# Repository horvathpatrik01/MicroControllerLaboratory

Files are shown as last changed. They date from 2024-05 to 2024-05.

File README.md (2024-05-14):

BME AUT University project

<b>Ambient lighting</b>

Task: \
Create an additional hardware unit for the STM32 NUCLEO-F446RE kit, which is programmable mood lighting with three high brightness RGB LEDs.

Requirements: \
&nbsp;&nbsp;&nbsp;&nbsp;-The executable lighting programs should be editable on PC, the hardware should communicate with PC via serial port. The serial
virtual serial port for serial communication, which can be connected to the USB port on the USB port! \
&nbsp;&nbsp;&nbsp;&nbsp;-The programs created in this way are stored in an I2C EEPROM or SPI Flash memory. \
&nbsp;&nbsp;&nbsp;&nbsp;-The device should be able to generate an emulation program without programming, which the nature of which can be set by means of a push-button. \
&nbsp;&nbsp;&nbsp;&nbsp;-Use the same button to switch between downloaded lighting programs. \
&nbsp;&nbsp;&nbsp;&nbsp;-Design, construction and installation of the circuit prepare a test program system for demonstration purposes to demonstrate the device, including a microcontroller program to ensure proper operation and a PC client program.

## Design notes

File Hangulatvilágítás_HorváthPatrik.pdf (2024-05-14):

# Hangulatvilágítás

Horváth Patrik

Feladat:

Készítsen kiegészítő hardver egységet az STM32 NUCLEO-F446RE kithez, amely programozható hangulatvilágítást valósít meg három nagy fényerejű RGB LED segítségével. A végrehajtható világítás-programok PC-n szerkeszthetőek legyenek, a hardver soros porton kommunikáljon a PC-vel. A soros kommunikációhoz virtuális soros portot használjon, melyet a kiten megtalálható USB port segítségével valósítson meg! Az így létrehozott programokat tárolja egy I2C EEPROM vagy SPI Flash memóriában. Az eszköz legyen képes programozás nélkül is hangulatfény programot generálni, amely jellege egy nyomógomb segítségével állítható. Ugyanezen gomb segítségével tudjon váltani a letöltött világítás-programok között. Az áramkör megtervezése, megépítése és üzembe helyezése után készítsen el egy, az eszköz bemutatására szolgáló demonstrációs célú tesztprogram rendszert, amely magában foglalja a megfelelő működést biztosító mikrokontrolleres programot, illetve egy PCs kliensprogramot.

## PCB

A tápot egy 300uF-os alu-elko szűrőkondenzátoron keresztül csatlakoztattam a mikrokontroller E5V lábához, a két nyomógombot egy-egy 1 kOhm-os ellenálláson keresztül felhúztam 3,3V-ra.

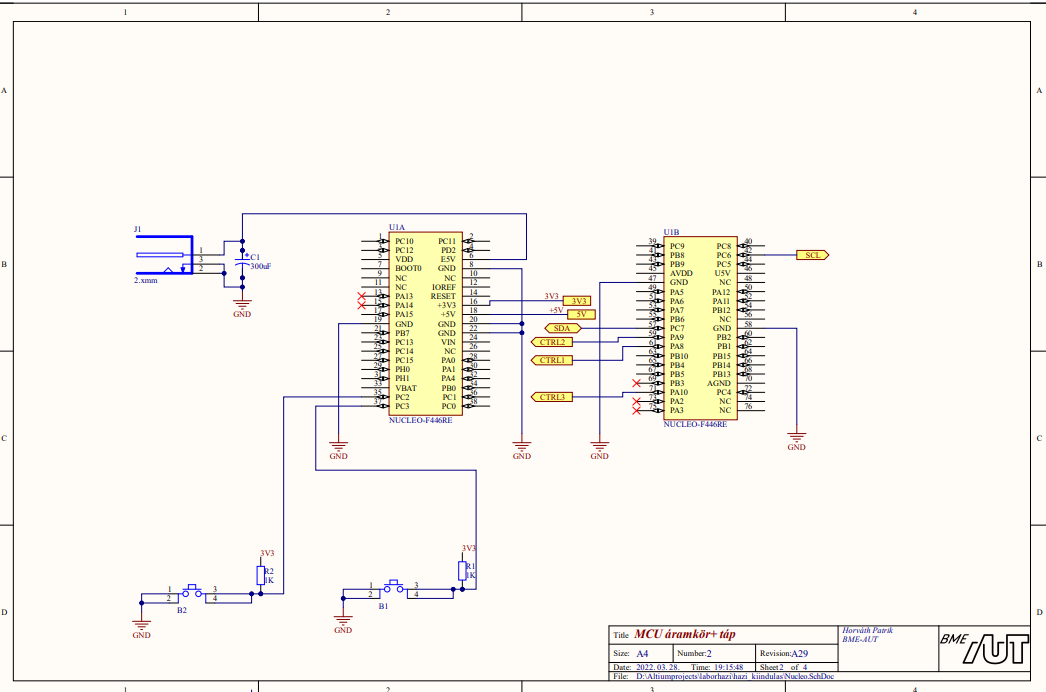
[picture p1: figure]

A ledek vezérlését Buck típusú LED Driverekkel valósítottam meg, amelyeknél a ledek áramát 100%-os kivezérlés mellett egy ellenállással lehet beállítani I=0.1/R A, ebből a képletből a közel 350mA beállításához 0,33 Ohmos ellenállásokra volt szükség. A fényerő vezérlését a CTRL lábra kötött PWM jellel lehet megvalósítani, amely nálam a TIMER1 1-es,2-es és 3-as csatornáiról érkeznek.

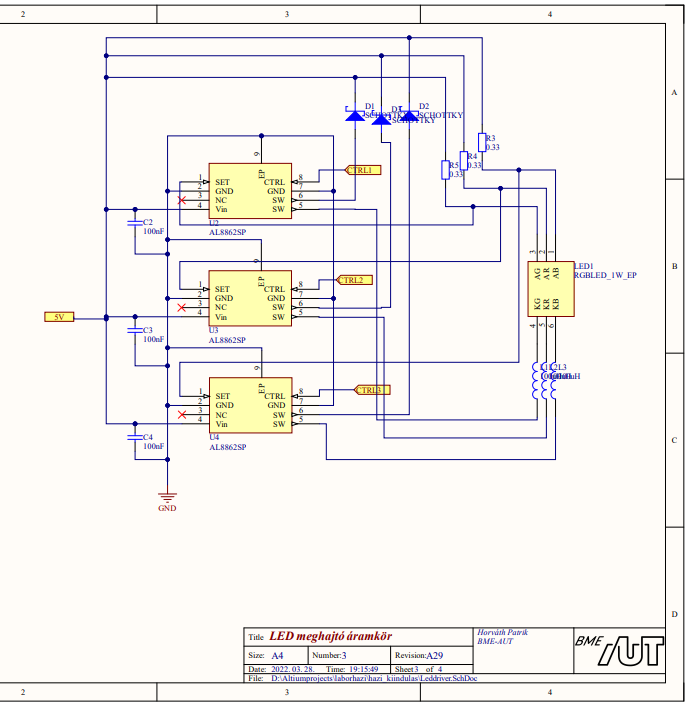
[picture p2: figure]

Az adatok tárolásához egy EEPROM-ot használtam, amely I2C-n keresztül képes adatokat küldeni illetve fogadni. Az A0-A2 lábait földre kötöttem így a 0xA0 címen lehet megcímezni. Az SDA és SCL lábakat egy-egy 10kOhmos ellenálláson keresztül fel kell húzni a tápfeszültségre az I2C működési elve miatt.

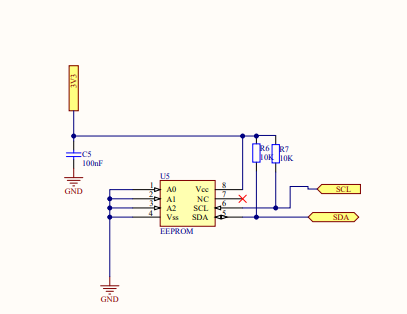
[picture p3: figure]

## Mikrokontroller firmware

A főciklusban elindítjuk a timereket, amelyeket a Ledek PWM beállítására, valamint a gombok pergésmentesítésének megoldására használunk. Ezenkívül folyamatosan meghívjuk az uartkezelő függvényt és ha szükséges akkor lekezeljük az érkezett adatokat. Az UART-on keresztül 19 bájt érkezik, és az első alapján eldönthetjük, hogy mit szeretnénk csinálni a többivel. Az utolsó két bájt az ellenőrző összeg felső és alsó 8 bitje. Ennek segítségével könnyedén ellenőrizhetjük, hogy érvényes adatokat fogadtunk-e, és ha igen akkor végrehajtjuk az utasításokat.

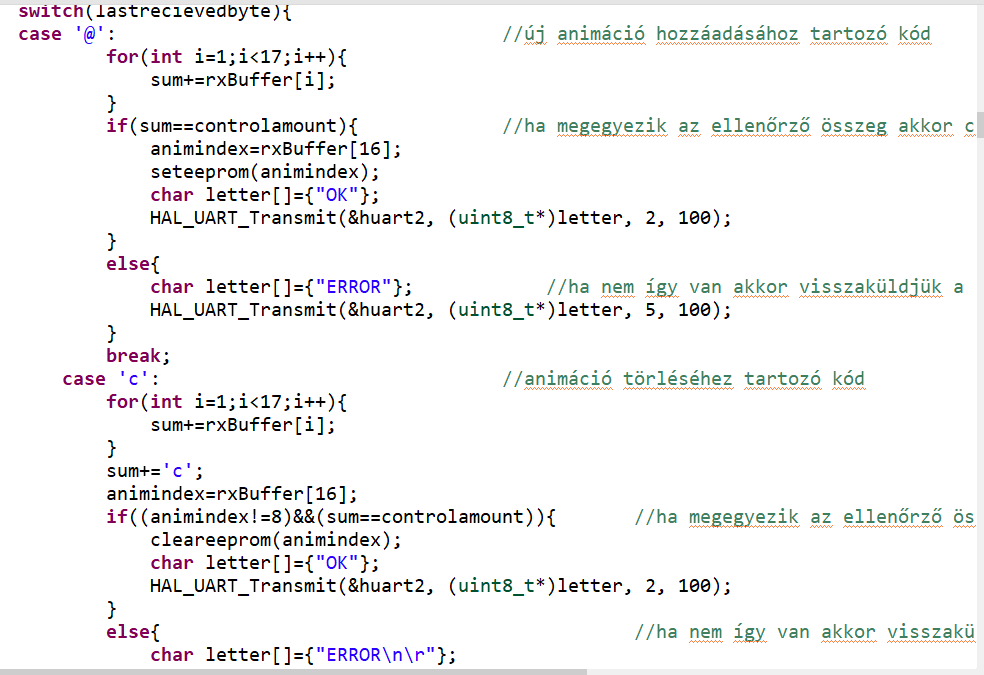
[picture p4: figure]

Nemutolsósorban pedig az animation függvényben megvizsgáljuk, hogy épp az eepromból vagy pedig előre megírt animációk közül választunk és ez alapján beállítjuk a ledeket. A kiválasztást a két nyomógombbal tudjuk elvégezni.

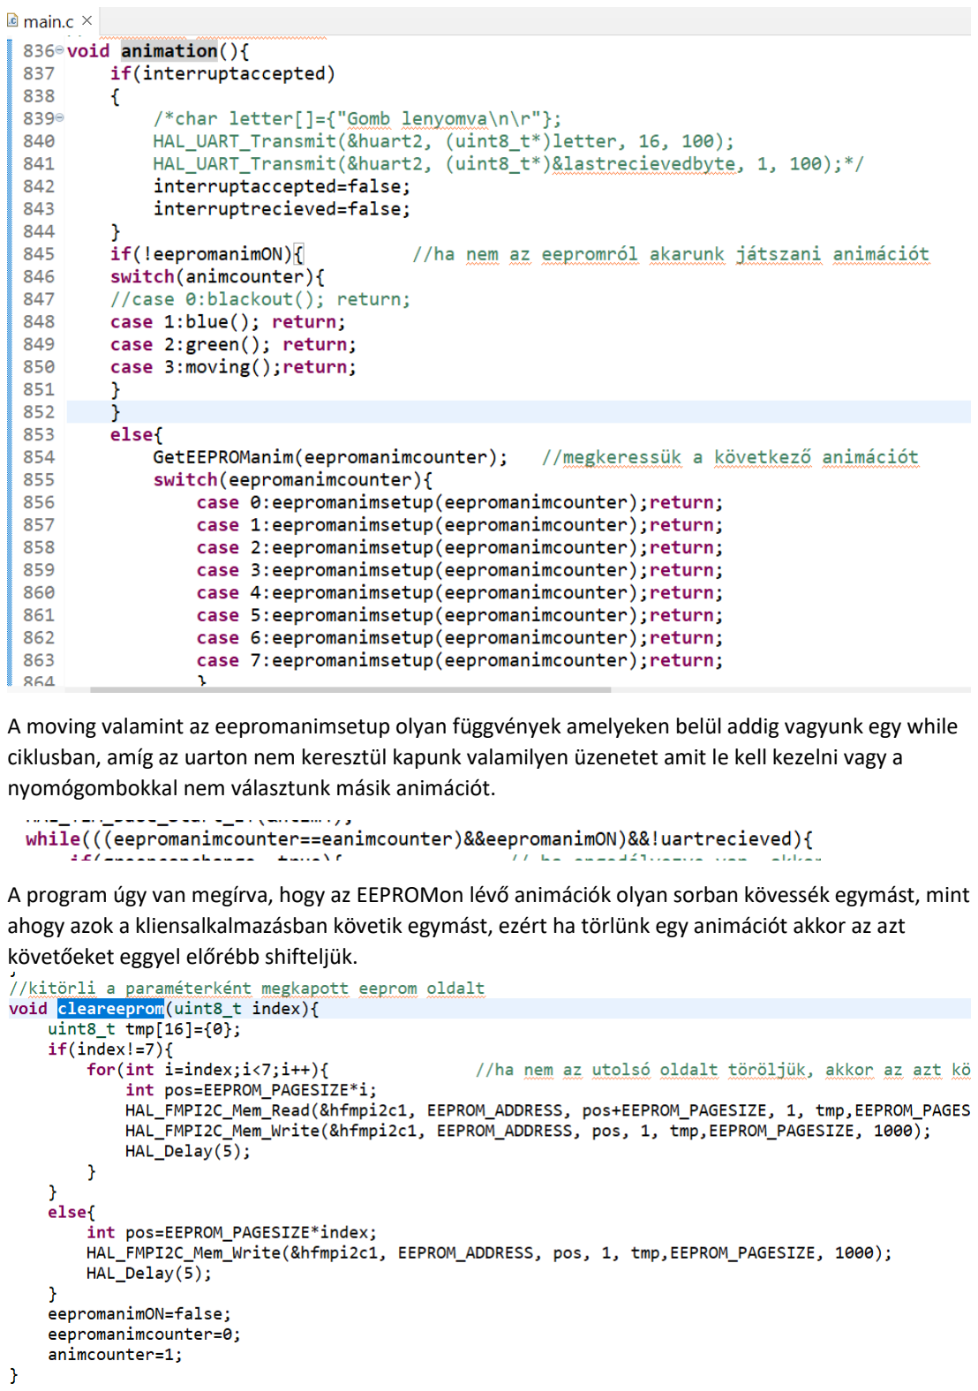
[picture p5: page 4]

A moving valamint az eepromanimsetup olyan függvények amelyeken belül addig vagyunk egy while ciklusban, amíg az uarton nem keresztül kapunk valamilyen üzenetet amit le kell kezelni vagy a nyomógombokkal nem választunk másik animációt.

A program úgy van megírva, hogy az EEPROMon lévő animációk olyan sorban kövessék egymást, mint ahogy azok a kliensalkalmazásban követik egymást, ezért ha törlünk egy animációt akkor az azt követőeket eggyel előrébb shifteljük.

## Kliensalkalmazás

Az alkalmazás megnyitása után a Settings fülön belül kiválaszthatjuk hogy melyik csatlakoztatott Portot szeretnénk használni a soros adatátvitelhez. A portokat frissítő programrészt egy timer event hív meg.

Ha a csatlakozás után készítünk egy új animációt az Animations>>New menüfül alatt akkor a Load gombunk elérhetővé válik.

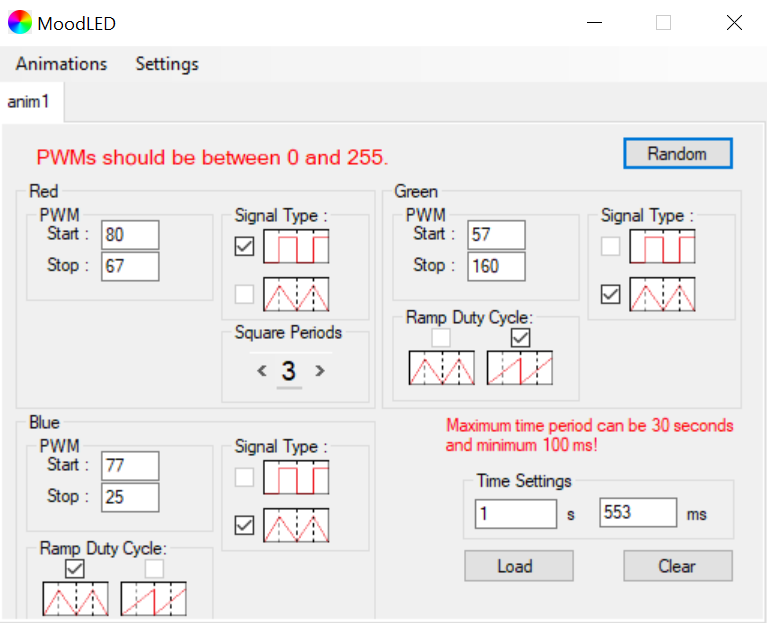
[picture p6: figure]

Itt a Random gombot használva véletlenszerű értékeket tölthetünk be a programba vagy akár manuálisan is átírhatjuk az értékeket benne. Fontos hogy minden négyzetbe írni kell valamilyen számot/ be kell pipálni különben hibát kapunk. A Clear gombbal a beírt értékeket törölhetjük.

A Load gombot használva elküldhetjük a mikrokontroller felé a beállításokat amely-re kapunk valamilyen választ attól függően hogy a művelet hogyan sikerült.

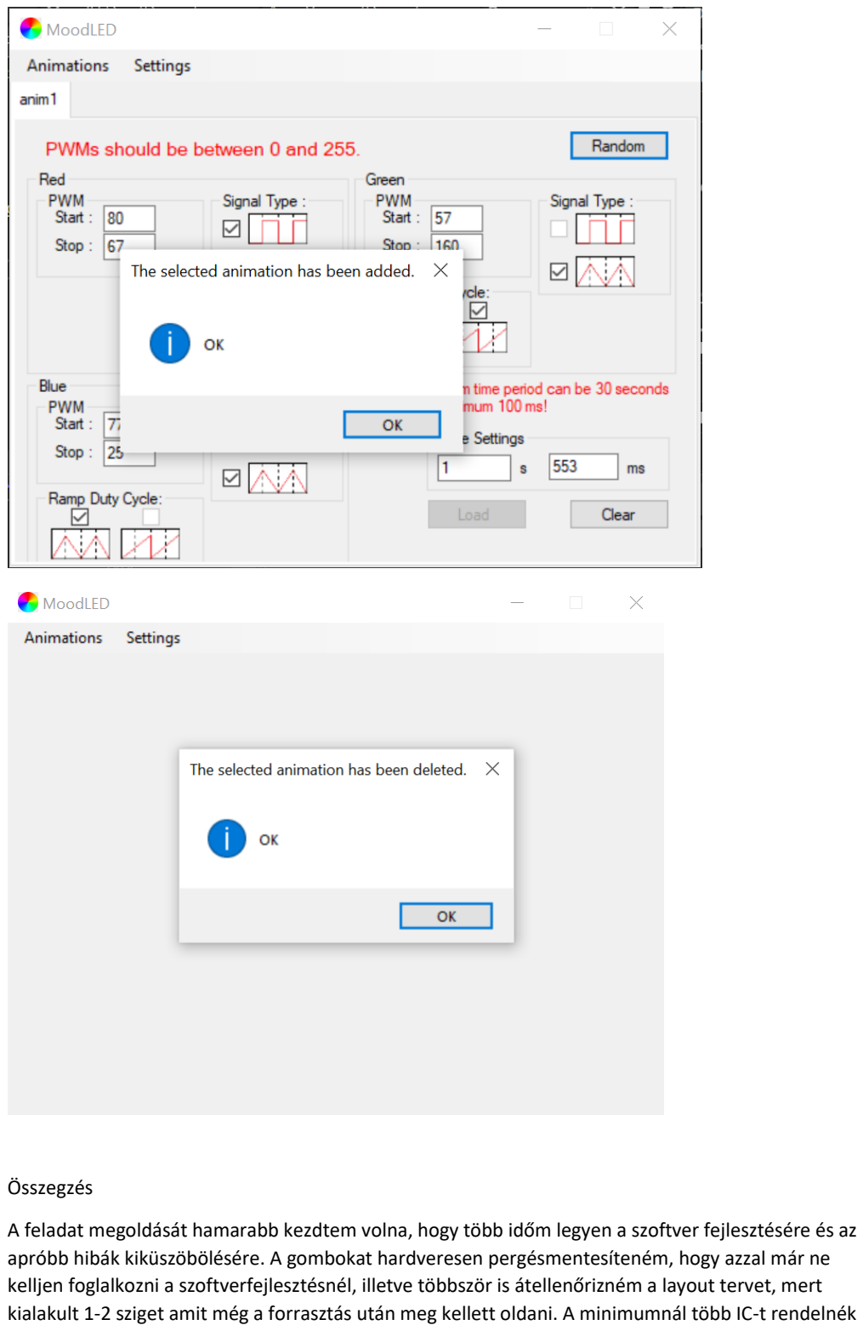
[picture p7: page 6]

Összegzés

A feladat megoldását hamarabb kezdtem volna, hogy több időm legyen a szoftver fejlesztésére és az apróbb hibák kiküszöbölésére. A gombokat hardveresen pergésmentesíteném, hogy azzal már ne kelljen foglalkozni a szoftverfejlesztésnél, illetve többször is átellenőrizném a layout tervet, mert kialakult 1-2 sziget amit még a forrasztás után meg kellett oldani. A minimumnál több IC-t rendelnék és nemcsak a kisebb ellenállásokból, ha esetleg valamilyen hiba fordulna elő akkor ki lehessen cserélni.

A számítógépes alkalmazás továbbfejlesztése lehet például a több szál használata.

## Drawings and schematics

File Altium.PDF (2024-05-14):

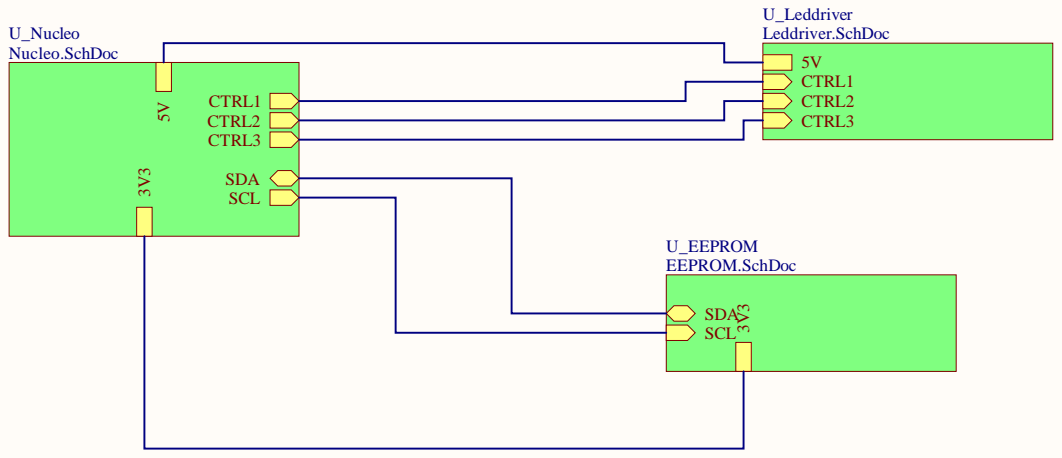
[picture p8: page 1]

D:\Altiumprojects\laborhazi\hazi_kiindulas\MainSheet.SchDoc

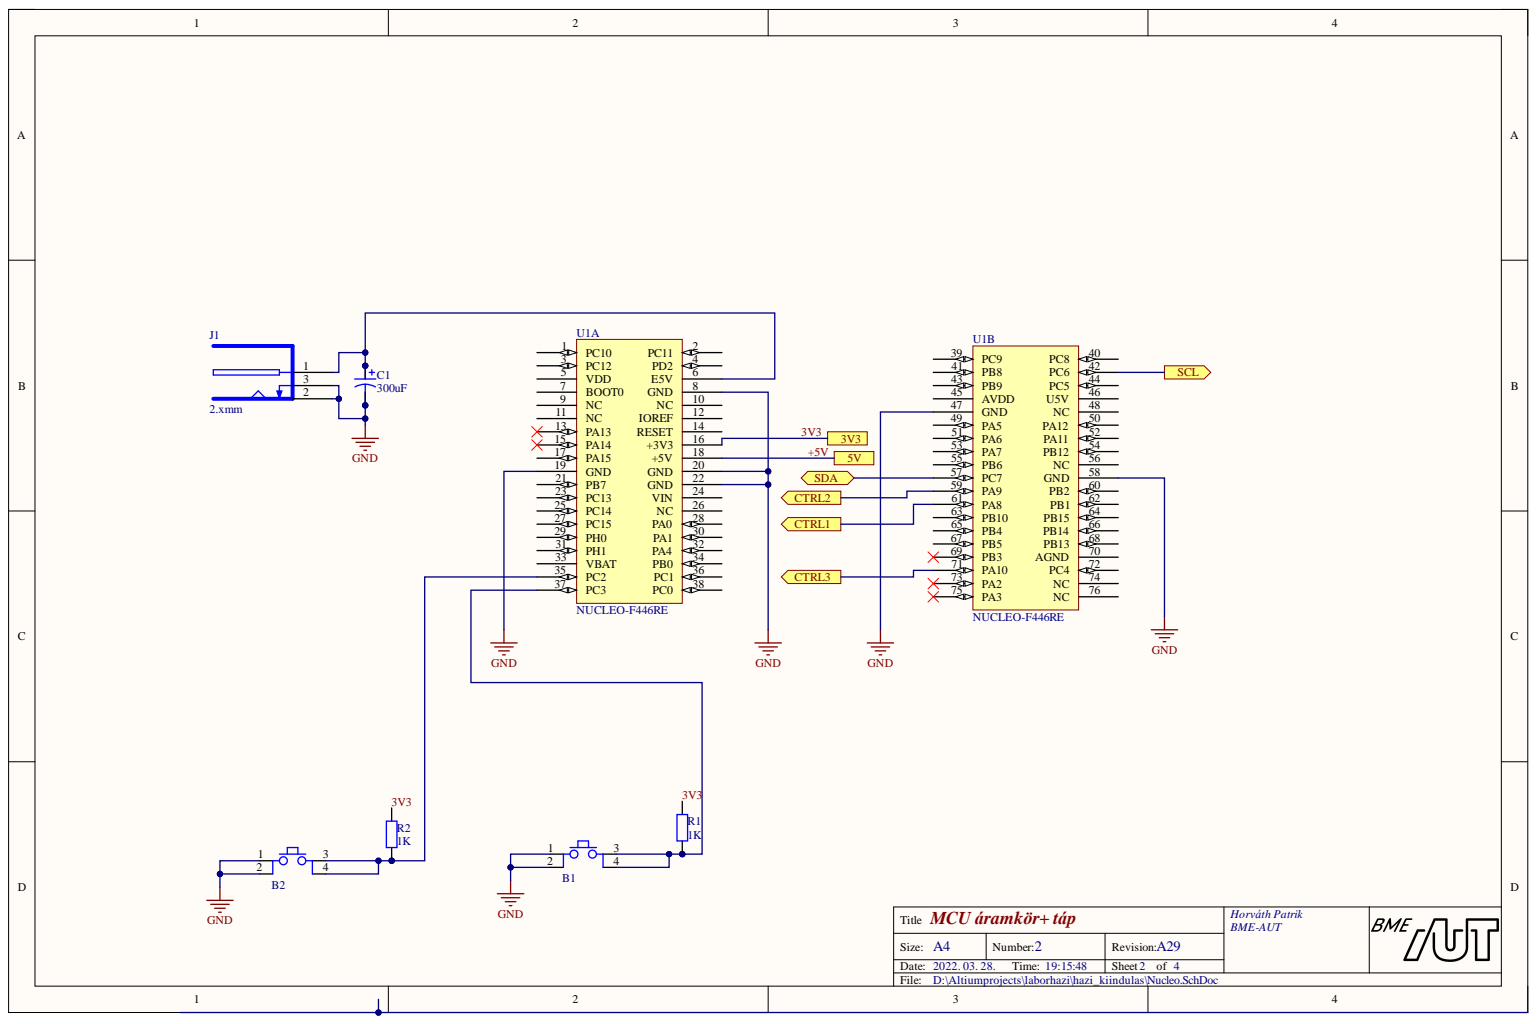
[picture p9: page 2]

D:\Altiumprojects\laborhazi\hazi_kiindulas\Nucleo.SchDoc

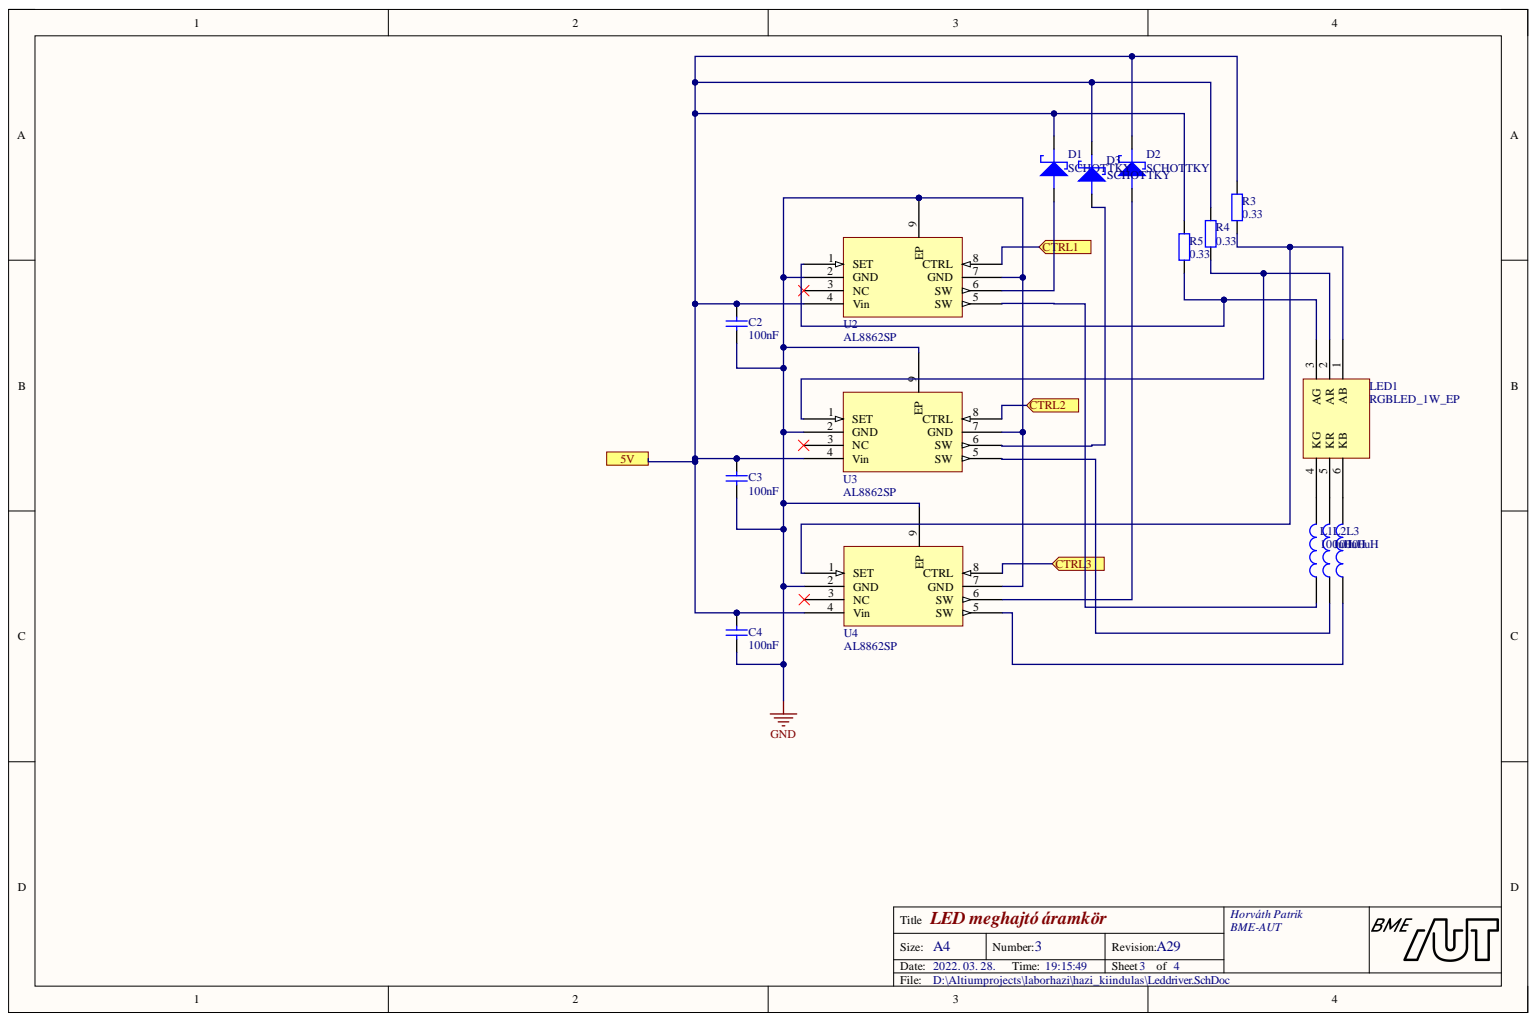
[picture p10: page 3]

1 | SE T | 5 SW 6 GND 7 CTRL E 8 P 9 | 0 . 3 3

3 | G N D N C Vi n

2 | G N D N C Vi n | 5 SW 6 GND 7 CTRL

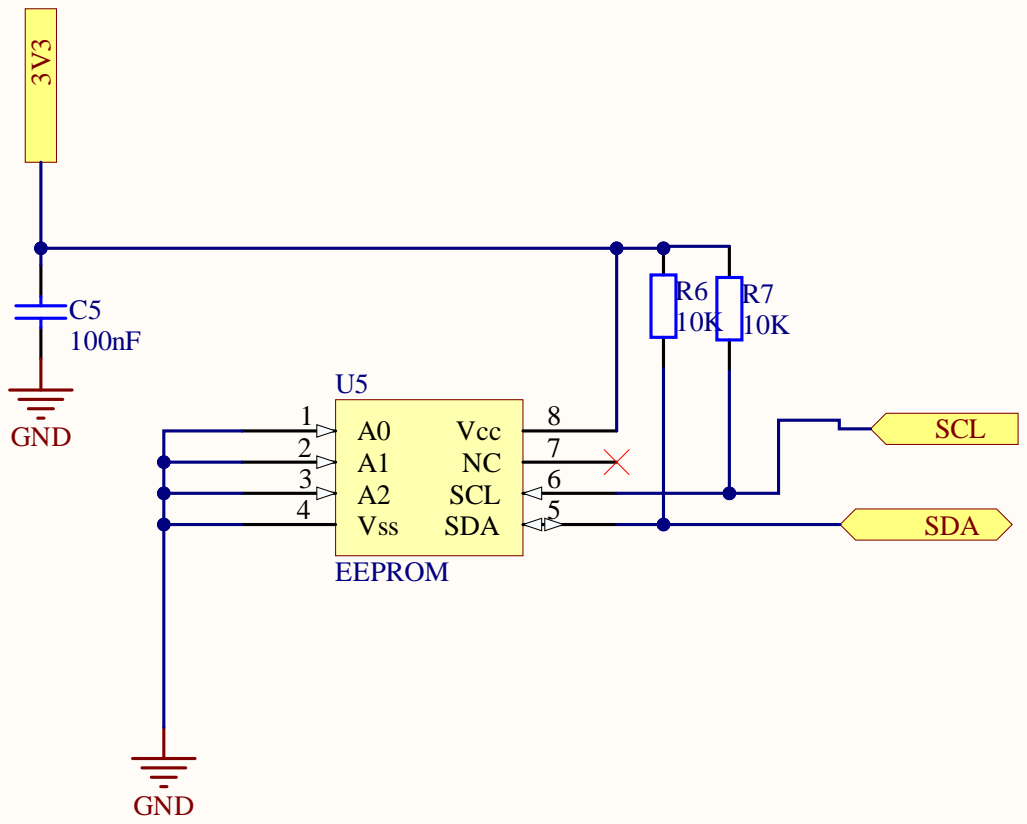
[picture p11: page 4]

2 | 5 SCL 6 NC 7 Vcc 8

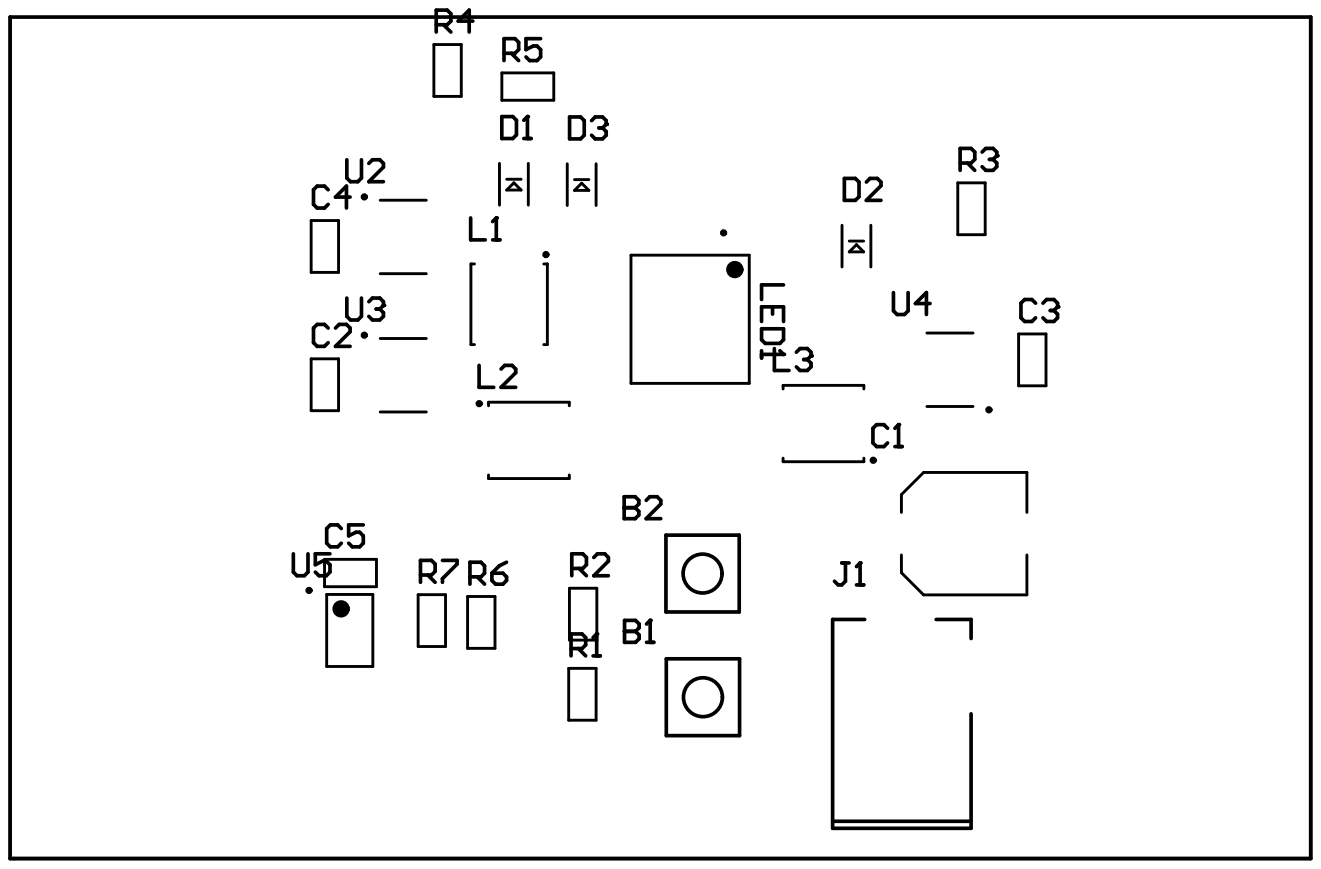
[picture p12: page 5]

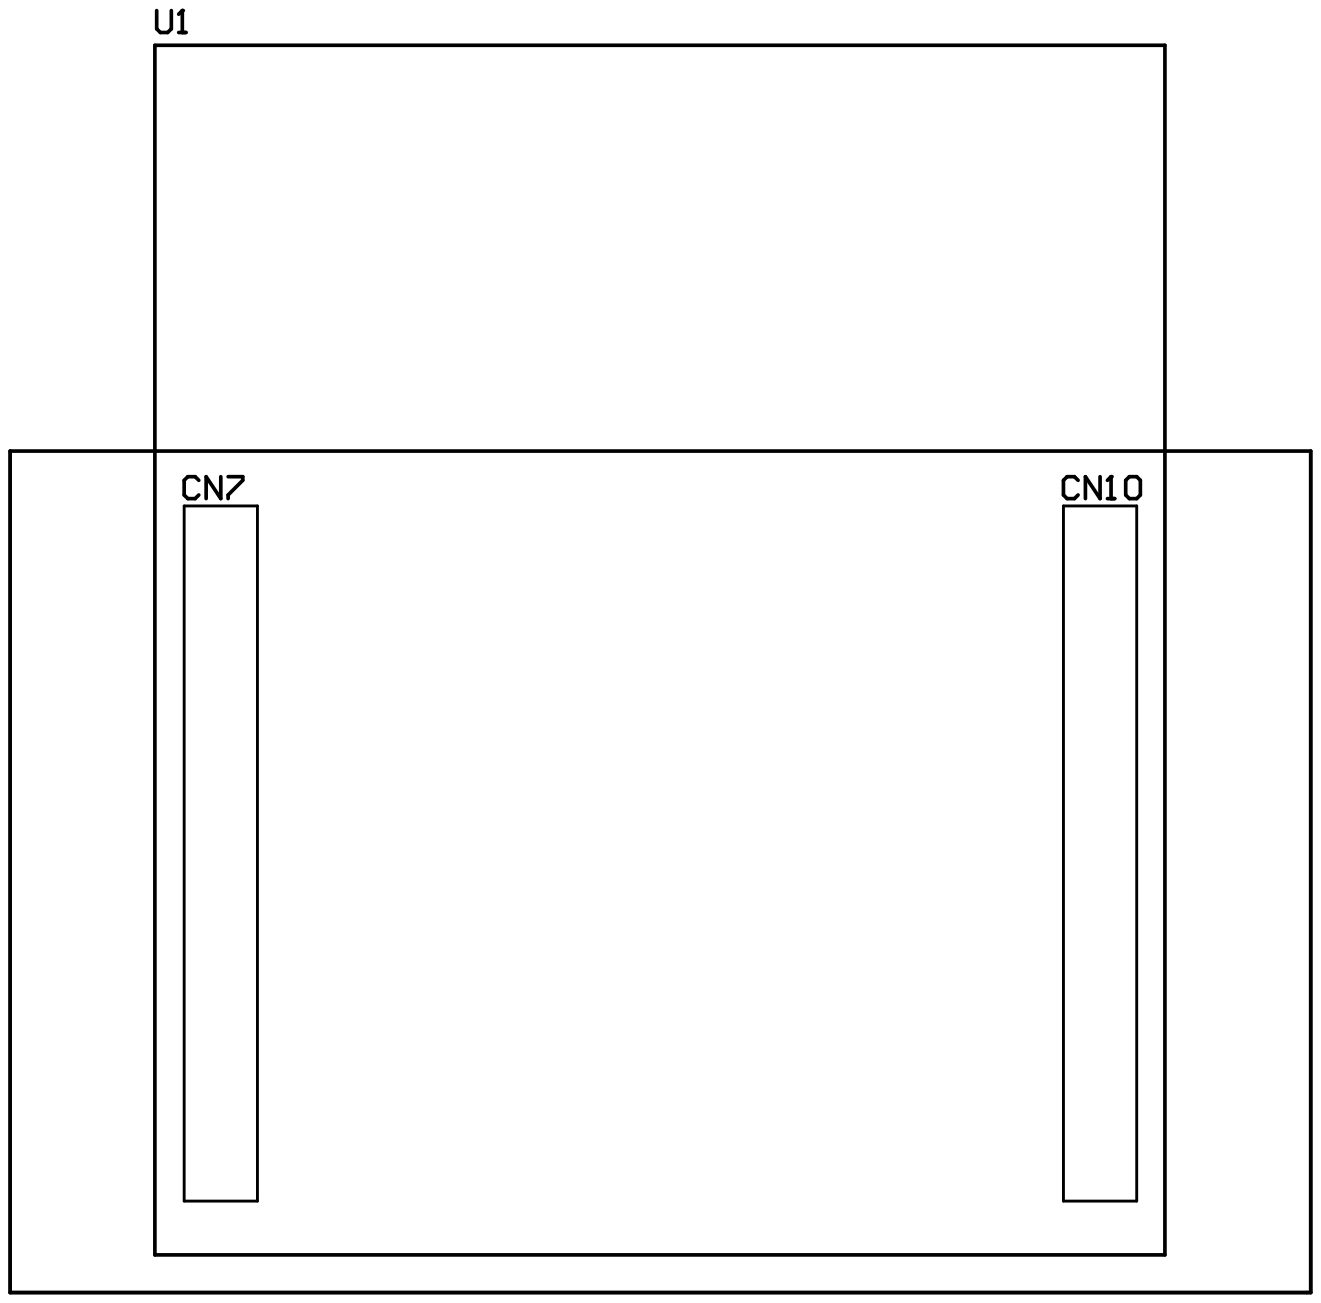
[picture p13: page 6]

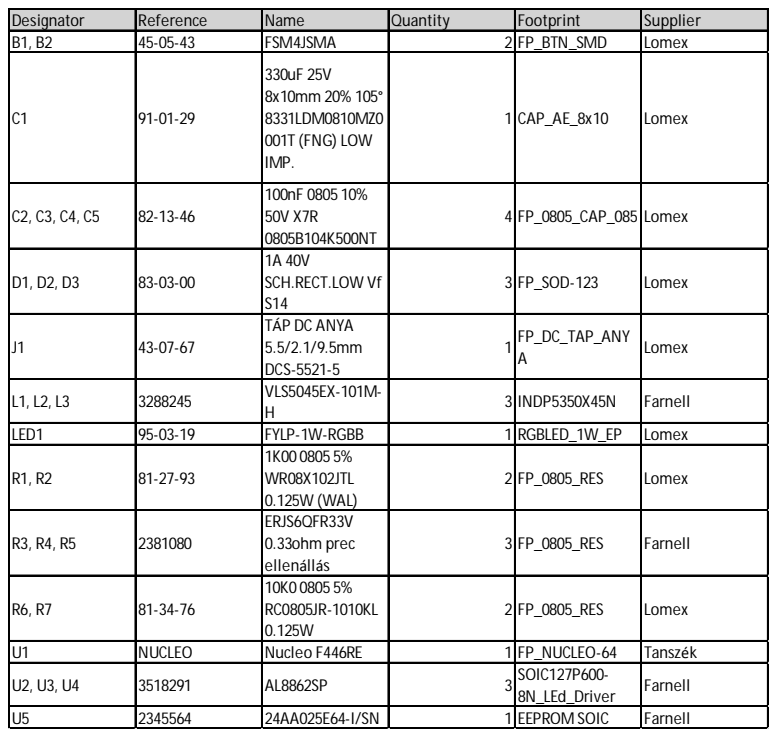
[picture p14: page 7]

Designator | Reference | Name | Quantity | Footprint | Supplier
B1, B2 | 45-05-43 | FSM4JSMA | 2 FP_BTN_SMD | | Lomex

C1 | 91-01-29 | 330uF 25V 8x10mm 20% 105° 8331LDM0810MZ0 001T (FNG) LOW IMP. | 1 CAP_AE_8x10 | | Lomex

C2, C3, C4, C5 | 82-13-46 | 100nF 0805 10% 50V X7R 0805B104K500NT | 4 FP_0805_CAP_085 Lomex

D1, D2, D3 | 83-03-00 | 1A 40V SCH.RECT.LOW Vf S14 | 3 FP_SOD-123 | | Lomex

J1 | 43-07-67 | TÁP DC ANYA 5.5/2.1/9.5mm DCS-5521-5 | 1 FP_DC_TAP_ANY | A | Lomex

L1, L2, L3 | 3288245 | VLS5045EX-101M-H | 3 INDP5350X45N | | Farnell

LED1 | 95-03-19 | FYLP-1W-RGBB | 1 RGBLED_1W_EP | | Lomex
R1, R2 | 81-27-93 | 1K00 0805 5% WR08X102JTL 0.125W (WAL) | 2 FP_0805_RES | | Lomex

R3, R4, R5 | 2381080 | ERJS6QFR33V 0.33ohm prec ellenállás | 3 FP_0805_RES | | Farnell

R6, R7 | 81-34-76 | 10K0 0805 5% RC0805JR-1010KL 0.125W | 2 FP_0805_RES | | Lomex

U1 | NUCLEO | Nucleo F446RE | 1 FP_NUCLEO-64 | | Tanszék
U2, U3, U4 | 3518291 | AL8862SP | 3 SOIC127P600- | 8N_LEd_Driver | Farnell

U5 | 2345564 | 24AA025E64-I/SN | 1 EEPROM SOIC | | Farnell

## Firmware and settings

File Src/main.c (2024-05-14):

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
/* Includes ------------------------------------------------------------------*/
#include "main.h"

/* USER CODE BEGIN Includes */
#include<stdbool.h>
#include<string.h>
#include<stdlib.h>
#include <inttypes.h>
/* USER CODE END Includes */

/* USER CODE BEGIN PD */
#define EEPROM_ADDRESS 0xA0  //base address for the eeprom
#define EEPROM_PAGESIZE 16	//16 bytes per page
#define EEPROM_PAGES 8		//8 pages
/* USER CODE END PD */

 FMPI2C_HandleTypeDef hfmpi2c1;

TIM_HandleTypeDef htim1;
TIM_HandleTypeDef htim2;
TIM_HandleTypeDef htim3;
TIM_HandleTypeDef htim4;

UART_HandleTypeDef huart2;

/* USER CODE BEGIN PV */
uint8_t animcounter=0;
uint8_t eepromanimcounter=0;
uint8_t eepromcurrentanim[16]={0};
uint8_t greenvalue=0;
uint8_t bluevalue=0;
bool currentInputUB=true;
bool currentInputLB=true;
bool interruptaccepted=false;
bool interruptrecieved=false;
bool greencanchange=true;
bool bluecanchange=true;
bool uartrecieved=false;
uint8_t inputcheckcounter=0;
uint8_t dataRead[128]={0};
uint8_t dataWrite[128];
bool eepromanimON=false;
char lastrecievedbyte=0;
uint8_t animindex=8;
uint8_t rxBuffer[200]={0};
/* USER CODE END PV */

void SystemClock_Config(void);
static void MX_GPIO_Init(void);
static void MX_USART2_UART_Init(void);
static void MX_TIM2_Init(void);
static void MX_FMPI2C1_Init(void);
static void MX_TIM1_Init(void);
static void MX_TIM3_Init(void);
static void MX_TIM4_Init(void);
/* USER CODE BEGIN PFP */
static void setPWM(TIM_HandleTypeDef, uint32_t, uint16_t, uint16_t);
static void HandleUart();
void GetEepromAnim(uint8_t);
void blackout();
void blue();
void green();
void moving();
void animation();
void eepromAnimSetup(uint8_t);
void clearEeprom(uint8_t);
void setEeprom(uint8_t);

int round_closest(int, int);
/* USER CODE END PFP */

/* USER CODE BEGIN 0 */
//PWM beállítása a paraméterben megkapott timer channel részére
static void setPWM(TIM_HandleTypeDef timer,uint32_t channel,uint16_t period ,uint16_t pulse)
{
	HAL_TIM_PWM_Stop(&timer, channel);
	TIM_OC_InitTypeDef sConfigOC;
	/*timer.Init.Period = period;
	HAL_TIM_PWM_Init(&timer);*/

	sConfigOC.OCMode = TIM_OCMODE_PWM1;
	sConfigOC.Pulse = pulse;
    sConfigOC.OCPolarity = TIM_OCPOLARITY_HIGH;
	sConfigOC.OCNPolarity = TIM_OCNPOLARITY_HIGH;
	sConfigOC.OCFastMode = TIM_OCFAST_DISABLE;
	sConfigOC.OCIdleState = TIM_OCIDLESTATE_RESET;
	sConfigOC.OCNIdleState = TIM_OCNIDLESTATE_RESET;
	if (HAL_TIM_PWM_ConfigChannel(&timer, &sConfigOC, channel) != HAL_OK)
	  {
	    Error_Handler();
	  }
	HAL_TIM_PWM_Start(&timer, channel);

}

//uarton érkező adat kezelése
static void HandleUart(){
	uint16_t sum=0;
	uint16_t controlamount;
	if(uartrecieved){									//abban az esetben ha érkezett adatt
		if(lastrecievedbyte!=0){						//és a beérkezett adat első eleme nem 0
			controlamount=rxBuffer[17]<<8;				//ellenőrző összeg visszaalakítása
			controlamount=controlamount|rxBuffer[18];
			switch(lastrecievedbyte){
			case '@':									//új animáció hozzáadásához tartozó kód
					for(int i=1;i<17;i++){
						sum+=rxBuffer[i];
					}
					if(sum==controlamount){				//ha megegyezik az ellenőrző összeg akkor csinálunk bármit is.
						animindex=rxBuffer[16];
						setEeprom(animindex);
						char letter[]={"OK"};
						HAL_UART_Transmit(&huart2, (uint8_t*)letter, 2, 100);
					}
					else{
						char letter[]={"ERROR"};			//ha nem így van akkor visszaküldjük a PC-nek hogy hiba van
						HAL_UART_Transmit(&huart2, (uint8_t*)letter, 5, 100);
					}
					break;
				case 'c':								//animáció törléséhez tartozó kód
					for(int i=1;i<17;i++){
						sum+=rxBuffer[i];
					}
					sum+='c';
					animindex=rxBuffer[16];
					if((animindex!=8)&&(sum==controlamount)){		//ha megegyezik az ellenőrző összeg akkor csinálunk bármit is.
						clearEeprom(animindex);
						char letter[]={"OK"};
						HAL_UART_Transmit(&huart2, (uint8_t*)letter, 2, 100);
					}
					else{											//ha nem így van akkor visszaküldjük a PC-nek hogy hiba van
						char letter[]={"ERROR\n\r"};
						HAL_UART_Transmit(&huart2, (uint8_t*)letter, 5, 100);
					}
					break;
				}
				lastrecievedbyte=0;
			}
			for(int i=0;i<20;i++){		//buffer kinullázása, habár nem szükséges
				rxBuffer[i]=0;
			}
			uartrecieved=false;
			HAL_UART_Receive_IT(&huart2, (uint8_t*)rxBuffer, 19);		//új parancsra várakozás
			}
}
//következő animáció kiválasztása, megkeresi a következő animációt az eepromban
void GetEepromAnim(uint8_t animcounter){
	uint8_t pos=animcounter*EEPROM_PAGESIZE;
	HAL_FMPI2C_Mem_Read(&hfmpi2c1, EEPROM_ADDRESS, pos, 1, eepromcurrentanim, EEPROM_PAGESIZE, 100);
	int counter=0;
	while(eepromcurrentanim[0]==0 && counter<8){// abban az esetben ha a kiválasztott oldalon nem lenne animáció akkor megkeressük a következőt ahol van
		counter++;
		eepromanimcounter++;
		if(eepromanimcounter==8)
			eepromanimcounter=0;
		pos=eepromanimcounter*EEPROM_PAGESIZE;
		HAL_FMPI2C_Mem_Read(&hfmpi2c1, EEPROM_ADDRESS, pos, 1, eepromcurrentanim, EEPROM_PAGESIZE, 100);
		if(eepromcurrentanim[0]!=0){ //ha megtaláltuk kilépünk

			break;
		}

	}
	return;
}
int round_closest(int divident, int divider){
	return ((divident+(divider/2))/divider);
}
//kitörli a paraméterként megkapott eeprom oldalt
void clearEeprom(uint8_t index){
	uint8_t tmp[16]={0};
	if(index!=7){
		for(int i=index;i<7;i++){				//ha nem az utolsó oldalt töröljük, akkor az azt követőeket egyel előrébb tesszük
			int pos=EEPROM_PAGESIZE*i;
			HAL_FMPI2C_Mem_Read(&hfmpi2c1, EEPROM_ADDRESS, pos+EEPROM_PAGESIZE, 1, tmp,EEPROM_PAGESIZE, 1000);
			HAL_FMPI2C_Mem_Write(&hfmpi2c1, EEPROM_ADDRESS, pos, 1, tmp,EEPROM_PAGESIZE, 1000);
			HAL_Delay(5);
		}
	}
	else{
		int pos=EEPROM_PAGESIZE*index;
		HAL_FMPI2C_Mem_Write(&hfmpi2c1, EEPROM_ADDRESS, pos, 1, tmp,EEPROM_PAGESIZE, 1000);
		HAL_Delay(5);
	}
	eepromanimON=false;
	eepromanimcounter=0;
	animcounter=1;
}
//a paraméterként megkapott oldalt betölti az uarton kapott adatokkal
void setEeprom(uint8_t index){
	int pos=EEPROM_PAGESIZE*index;
	uint8_t tmp[16]={0};
	for(int i=0;i<EEPROM_PAGESIZE;i++){
			tmp[i]=rxBuffer[i+1];
	}
	HAL_FMPI2C_Mem_Write(&hfmpi2c1, EEPROM_ADDRESS, pos, 1, tmp, EEPROM_PAGESIZE, 1000);
	HAL_Delay(5);
}
/* USER CODE END 0 */

/**
  * @brief  The application entry point.
  * @retval int
  */
int main(void)
{
  /* MCU Configuration--------------------------------------------------------*/

  /* Reset of all peripherals, Initializes the Flash interface and the Systick. */
  HAL_Init();

  /* Configure the system clock */
  SystemClock_Config();

  /* Initialize all configured peripherals */
  MX_GPIO_Init();
  MX_USART2_UART_Init();
  MX_TIM2_Init();
  MX_FMPI2C1_Init();
  MX_TIM1_Init();
  MX_TIM3_Init();
  MX_TIM4_Init();
  /* USER CODE BEGIN 2 */
  HAL_TIM_PWM_Start(&htim1, TIM_CHANNEL_1);
  HAL_TIM_PWM_Start(&htim1, TIM_CHANNEL_2);
  HAL_TIM_PWM_Start(&htim1, TIM_CHANNEL_3);
  HAL_FMPI2C_Mem_Read(&hfmpi2c1, EEPROM_ADDRESS, 0, 1, dataRead, 128, 1000);

  /* USER CODE END 2 */

  /* Infinite loop */
  /* USER CODE BEGIN WHILE */
  while (1)
  {
    /* USER CODE END WHILE */

    /* USER CODE BEGIN 3 */
	  HandleUart();
	  animation();
  }
  /* USER CODE END 3 */
}

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
/* USER CODE BEGIN 4 */

//Amikor az uarton keresztül beolvastunk 19 bájtot akkor fut le
void HAL_UART_RxCpltCallback(UART_HandleTypeDef *handle)
{
		lastrecievedbyte=rxBuffer[0];	//a kapott adatok közül ez lesz a parncsunk
		uartrecieved=true;
}
//Ha megnyomjuk valamelyik gombot akkor fut le
void HAL_GPIO_EXTI_Callback(uint16_t GPIO_PIN){
	if(!interruptrecieved)
	{
		interruptrecieved=true;
		if(GPIO_PIN == Buttonupper_Pin){	// ha  a megfelelő gpio pinről érkezett megszakítás akkor elindítjuk a 2-es timert
			HAL_TIM_Base_Start_IT(&htim2);
		}
		else if(GPIO_PIN == Buttonlower_Pin){
			HAL_TIM_Base_Start_IT(&htim2);
		}
	}

}
//bármely timer megszakításkezelője
void HAL_TIM_PeriodElapsedCallback(TIM_HandleTypeDef* htim)
{
	if(htim==&htim2){			//pergésmentesítés megoldása és animációk közötti váltás
	inputcheckcounter++;
	currentInputUB=HAL_GPIO_ReadPin(GPIOC, Buttonupper_Pin);
	currentInputLB=HAL_GPIO_ReadPin(GPIOC, Buttonlower_Pin);
	if(inputcheckcounter>=10&&(currentInputUB==false)){		//megvizsgáljuk hogy 10*5 ms-el később még mindig le van e nyomva a gomb és ha igen akkor változtatunk
		HAL_GPIO_TogglePin(GPIOA, GPIO_PIN_5);
		interruptaccepted=true;
		if(eepromanimON==true){
		eepromanimON=false;
		animcounter=0;
		blackout();
		}
		else
			animcounter++;
		inputcheckcounter=0;
		eepromanimcounter=0;
				if(animcounter==4){
				    animcounter=0;
				    blackout();
				    }
		HAL_TIM_Base_Stop_IT(&htim2);
	}
	else if(inputcheckcounter>=10&&(currentInputLB==false)){
		HAL_GPIO_TogglePin(GPIOA, GPIO_PIN_5);
		interruptaccepted=true;
		inputcheckcounter=0;
		if(eepromanimON==false){
			eepromanimON=true;
			eepromanimcounter=0;
		}
		else{
			eepromanimcounter++;
		}
		animcounter=0;
			if(eepromanimcounter==8){
				eepromanimcounter=0;
				blackout();
			}
		HAL_TIM_Base_Stop_IT(&htim2);
	}
	else if(inputcheckcounter>30){
		inputcheckcounter=0;
		interruptrecieved=false;
		HAL_TIM_Base_Stop_IT(&htim2);
	}
	}
	if(htim==&htim3){									//zöld led PWM beállítása
		 setPWM(htim1,TIM_CHANNEL_1 ,255,greenvalue);
		 greencanchange=true;
	}
	if(htim==&htim4){									//kék led PWM beállítása
		setPWM(htim1, TIM_CHANNEL_3, 255, bluevalue);
		bluecanchange=true;
	}

}
void blackout(){			//mindegyik LED kikapcsolása
	setPWM(htim1, TIM_CHANNEL_1, 255, 0);
	setPWM(htim1, TIM_CHANNEL_2, 255, 0);
	setPWM(htim1, TIM_CHANNEL_3, 255, 0);
	return;
}
void blue(){				//alap kék fény
	blackout();
	setPWM(htim1, TIM_CHANNEL_3, 255, 255);
	setPWM(htim1, TIM_CHANNEL_1, 255, 0);
	setPWM(htim1, TIM_CHANNEL_2, 255, 0);
	return;
}
void green(){				//alap zöld fény
	blackout();
	setPWM(htim1, TIM_CHANNEL_1, 255, 255);
	setPWM(htim1, TIM_CHANNEL_2, 255, 0);
	setPWM(htim1, TIM_CHANNEL_3, 255, 0);
	return;
}
void moving(){				//kék és zöld folyamatos váltogatása
	int g=0,b=255,dirg,dirb;
	while(animcounter==3&&!uartrecieved){ //egyszerű transition effekt, amíg nem kapunk uart üzenetet vagy nem változtatjuk meg az animációt
		if(g==255)
		  	dirg=-1;
		 if(g==0)
		  	dirg=1;
		 setPWM(htim1,TIM_CHANNEL_1 ,255,g);
		 g+=dirg;
		 if(b==255)
		  	dirb=-1;
		 if(b==0)
		  	dirb=1;
		 setPWM(htim1,TIM_CHANNEL_3 ,255,b);
		  	b+=dirb;
		HAL_Delay(10);
		  }
	return;

}

// animáció kiválasztása
void animation(){
	if(interruptaccepted)
	{
		interruptaccepted=false;
		interruptrecieved=false;
	}
	if(!eepromanimON){			//ha nem az eepromról akarunk játszani animációt
	switch(animcounter){
	//case 0:blackout(); return;
	case 1:blue(); return;
	case 2:green(); return;
	case 3:moving();return;
	}
	}
	else{
		GetEepromAnim(eepromanimcounter);	//megkeressük a következő animációt
		switch(eepromanimcounter){
			case 0:eepromAnimSetup(eepromanimcounter);return;
			case 1:eepromAnimSetup(eepromanimcounter);return;
			case 2:eepromAnimSetup(eepromanimcounter);return;
			case 3:eepromAnimSetup(eepromanimcounter);return;
			case 4:eepromAnimSetup(eepromanimcounter);return;
			case 5:eepromAnimSetup(eepromanimcounter);return;
			case 6:eepromAnimSetup(eepromanimcounter);return;
			case 7:eepromAnimSetup(eepromanimcounter);return;
			}
	}
	return;
}
//Az épp kiválasztott eeprom animációhoz tartozó beállítások
void eepromAnimSetup(uint8_t eanimcounter){
	if(eepromcurrentanim[0]==0){		//Ha az épp kiválasztott animációban nincsenek értelmes adatok amit az első bájt jelez akkor kikapcsoljuk a ledeket és kikapcsoljuk az eeprom animációkat.
		eepromanimON=false;
		blackout();
		return;
	}
	int dirg=1,dirb=1;				//beállítások kiolvasása az eepromcurrentanim-ból
	int dirgstart=dirg;
	int dirbstart=dirb;
	uint8_t greenstart=eepromcurrentanim[4],greenstop=eepromcurrentanim[5],greendirmode=eepromcurrentanim[6];
	uint8_t bluestart=eepromcurrentanim[7],bluestop=eepromcurrentanim[8],bluedirmode=eepromcurrentanim[9];
	greenvalue=greenstart;
	bluevalue=bluestart;
	int greenanimtype=eepromcurrentanim[13];
	int blueanimtype=eepromcurrentanim[14];
	int animationlength=eepromcurrentanim[10]*1000+eepromcurrentanim[11]*10;
	int greendelaytime;
	int bluedelaytime;
	if(!greenanimtype){		//zöld led timer megszakítások periódusidejének számítása.
		if(eepromcurrentanim[6])
			greendelaytime=animationlength/(2*abs(eepromcurrentanim[4]-eepromcurrentanim[5]));
		else
			greendelaytime=animationlength/abs(eepromcurrentanim[4]-eepromcurrentanim[5]);
	}
	else{
		greendelaytime=animationlength/greenanimtype;
	}

	if(!blueanimtype){		//kék led timer megszakítások periódusidejének számítása.
		if(eepromcurrentanim[9])
			bluedelaytime=animationlength/(2*abs(eepromcurrentanim[7]-eepromcurrentanim[8]));
		else
			bluedelaytime=animationlength/abs(eepromcurrentanim[7]-eepromcurrentanim[8]);
	}
	else{
		bluedelaytime=animationlength/blueanimtype;
	}
	htim3.Init.Prescaler = (2*greendelaytime);		//timer osztások beállítása

	if (HAL_TIM_Base_Init(&htim3) != HAL_OK)
	  {
	    Error_Handler();
	  }
	htim4.Init.Prescaler=(2*bluedelaytime);

	if (HAL_TIM_Base_Init(&htim4) != HAL_OK)
		  {
		    Error_Handler();
		  }
	if(eepromcurrentanim[4]>eepromcurrentanim[5])
		dirgstart=-1;
	if(eepromcurrentanim[7]>eepromcurrentanim[8])
		dirbstart=-1;
	setPWM(htim1,TIM_CHANNEL_1 ,255,greenstart);		//kezdőállapotok beállítása
	setPWM(htim1,TIM_CHANNEL_3 ,255,bluestart);
	dirg=dirgstart;
	dirb=dirbstart;
	HAL_TIM_Base_Start_IT(&htim3);				//Timer IT-k indítása
	HAL_TIM_Base_Start_IT(&htim4);
	while(((eepromanimcounter==eanimcounter)&&eepromanimON)&&!uartrecieved){			//Ha nem kaptunk üzenetet épp vagy nem választottunk ki másik animációt
		if(greencanchange==true){				// ha engedélyezve van, akkor változtathatunk a led beállításokon, hogy ne ugorjunk át állapotot két timer megszakítás között										//akkor egy végtelen ciklusban folyamatosan frissítjük a ledeket
			if(!greenanimtype){
			greenvalue+=dirg;
			if(greenvalue==greenstop){			// ha elérjük valamelyik végállapotot akkor váltunk annak megfelelően hogy milyen az animáció típusa(négyszög vagy háromszögjel)
				if(!greendirmode)
					greenvalue=greenstart;
				else
					dirg=-1*dirg;
			}
			if(greenvalue==greenstart){
				dirg=dirgstart;
			}
			}
			else{
				if(greenvalue==greenstart)
					greenvalue=greenstop;
				else
					greenvalue=greenstart;
			}
			greencanchange=false;
		}
		if(bluecanchange==true){			// ha engedélyezve van, akkor változtathatunk a led beállításokon, hogy ne ugorjunk át állapotot két timer megszakítás között
			if(!blueanimtype){
				bluevalue+=dirb;
				if(bluevalue==bluestop){
					if(!bluedirmode)
						bluevalue=bluestart;
					else
						dirb=-1*dirb;
				}
				if(bluevalue==bluestart){
					dirb=dirbstart;
				}
			}
			else{
				if(bluevalue==bluestart){
					bluevalue=bluestop;
				}
				else
					bluevalue=bluestart;
			}
					bluecanchange=false;
		}
	}
	HAL_TIM_Base_Stop_IT(&htim3);			//Timer megszakítások kikapcsolása
	HAL_TIM_Base_Stop_IT(&htim4);
}


/* USER CODE END 4 */
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

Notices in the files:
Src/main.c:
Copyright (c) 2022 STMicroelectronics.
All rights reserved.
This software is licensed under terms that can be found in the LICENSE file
